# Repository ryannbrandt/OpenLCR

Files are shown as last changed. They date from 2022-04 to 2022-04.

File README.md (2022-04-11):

# OpenLCR
The goal of this project is to produce an accurate, inexpensive, open-source LCR meter with an original design.

- What is an LCR meter?

A device that measures inductance (L), capacitance (C), and resistance (R).  Typically, LCR meters also measure secondary parameters of circuit components such as equivalent series resistance, quality factor, and leakage resistance.

- How are these quantities measured?

Generally, an LCR meter needs to measure impedance.  A common way of doing this is to apply a known voltage or current to the unknown device under test, and then measure the uncontrolled quantity (current or voltage, respectively) that results.  If the input is sinusoidal at a set frequency, the ratio of the voltage and current amplitudes gives the magnitude of the impedance.  The difference in phase between the two gives the phase of the impedance.  For metrology purposes, this measurement will often just be taken at a single precise frequency, such as 100 Hz, 120 Hz, 1 kHz, 10 kHz, or 100 kHz.  Alternatively, you can measure impedance at many different frequencies and generate a plot of Z vs f.  Either way, this information, combined with a model for the device under test, can be used to calculate model parameters.  In the simplest nontrivial case, a model may consist of a series inductance and resistance (in the case of an inductor), a series capacitance and resistance (in the case of a capacitor), or a network of series RL and parallel C (for a resistor).

- Why make an LCR meter?

I studied analog circuit design for most of my advanced coursework in electrical engineering.  More recently, I took some coursework in microcontrollers.  Along the way, I've gained an appreciation for measurement instrumentation.  I wanted to work on a project that combined all of these topics.  The challenge of precisely measuring component parameters is well-suited for this goal.  It has a well-defined problem and straightforward measurement technique, but the devil is in the details.  Finding suitable components, evaluating them for this application, and just making it work is a valuable exercise in system-level electronics design and prototyping.  Also, being able to take these measurements is useful when making circuits like filters (for which precisely matched resistors and capacitors are essential) or high-frequency circuits (for which characterizing parasitics is essential for accurate modeling).  Regardless of these practical applications for LCR meters, this measurement challenge is just fun!

- Don't low-cost LCR meters already exist?

Probably.  I did a bit of market research at the beginning of this project and was able to find devices that measure L, C, and R along with secondary parameters and even transistor and diode characterization for as little as $30 on Amazon.  The accuracy of such low-cost instruments is not clear though (they make no claims regarding accuracy, have no calibration certification, and contain no datasheet or user manuals), though most devices only display enough information to possibly provide 1% accuracy.  One $30 device I found can measure inductance from 10 uH to 20 H, capacitance from 25 pF to 0.1 F, and resistance from 0.5 ohm to 50 Mohm.  Higher quality devices appear to be available such as battery-powered, handheld, calibrated instruments for $300-$500, including smart tweezers (meant for characterizing primary characteristics and parasitics of surface mount components).  Those instruments claim accuracy on the order of 0.3%.  The range of measured values is something like 1 uH to 1000H for inductors, and unspecified for C and R.  Finally, the highest quality devices are bench-top, rack-mounted, metrology-grade LCR meters.  These devices range in cost from $3,000 (usually used) to $12,000.  Their accuracy is as high as 0.02%, can measure 0.01 mohms to 10 Tohms for R, 0.1 pH to 10GH for L, and 0.1 zF to 10 kF for C.  
[Source](https://www.ietlabs.com/pdf/Datasheets/1693.pdf)

I think it will be interesting to see how accurate of an instrument I can make using a modest budget.  Let's find out!

## Design  (Last updated 4/10/2022)

Here are the circuit schematics for the latest version of the design:

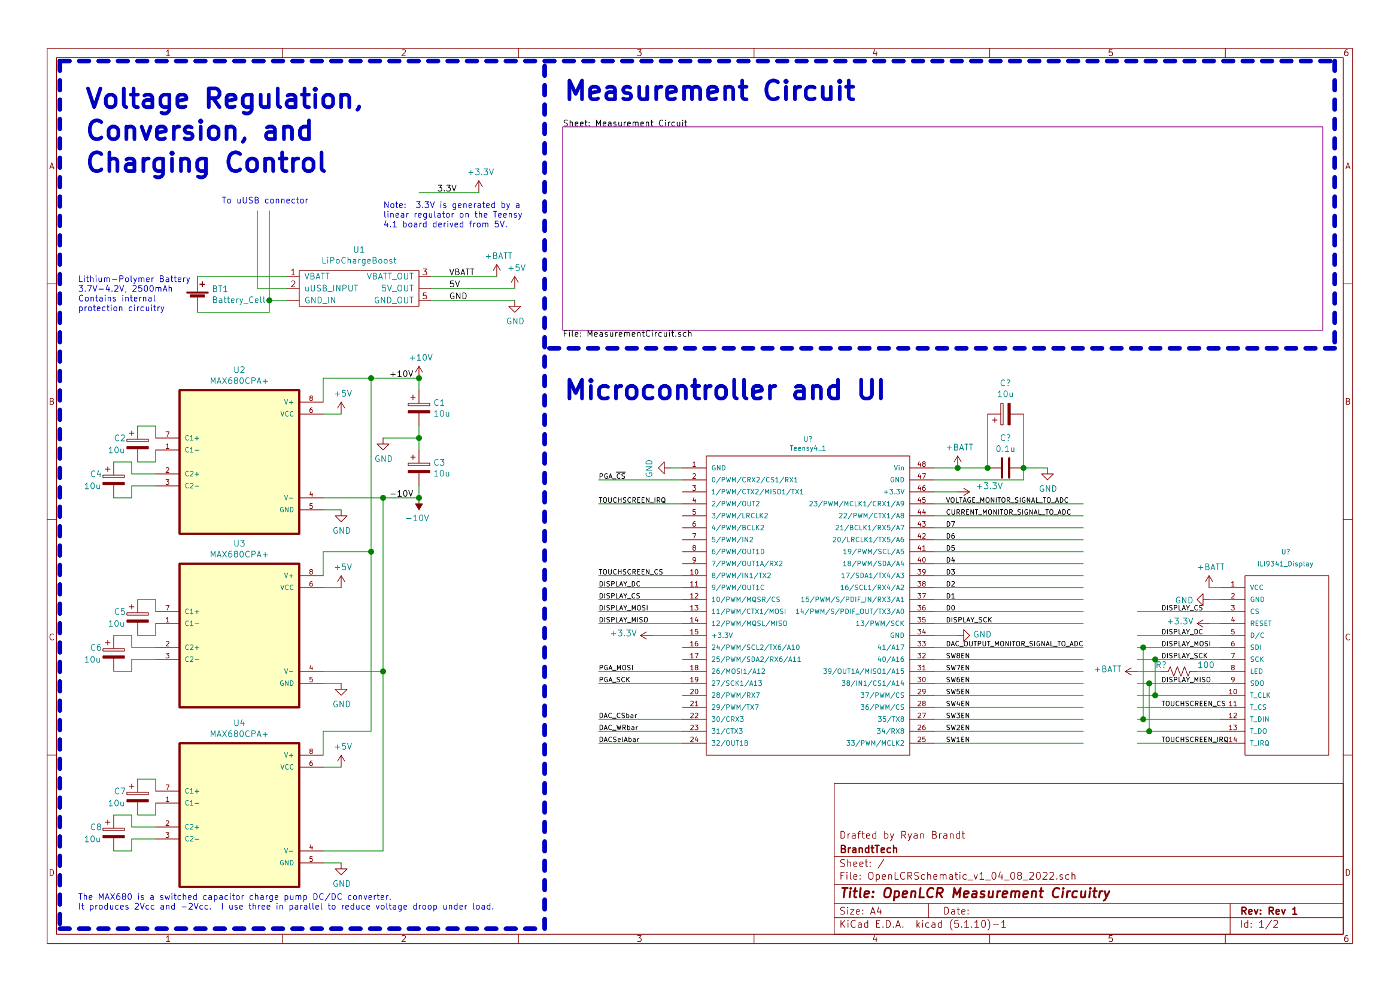
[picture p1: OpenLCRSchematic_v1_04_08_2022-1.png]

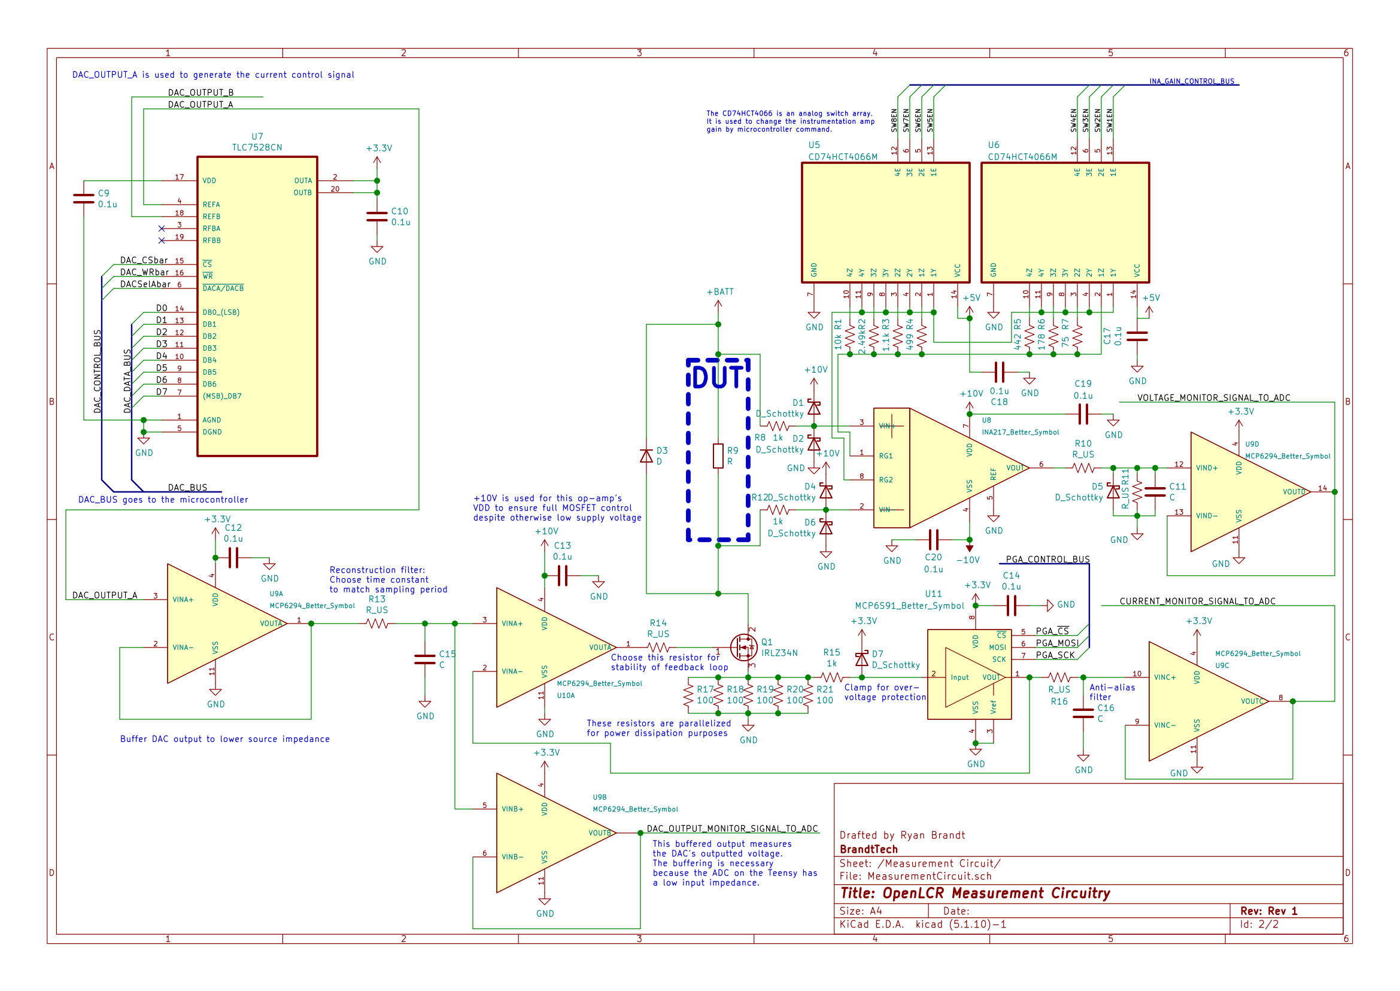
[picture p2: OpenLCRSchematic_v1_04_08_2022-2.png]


A short description of the principle of operation is this:

To measure impedance, the instrument acts as a current source to the device under test.  The voltage across the DUT that results is measured using an instrumentation amplifier.  The current through the device is measured by measuring the voltage across a shunt resistor that is in series with the DUT.  The current source is controllable by a voltage that is generated by a digital to analog converter.  The voltage generated by the DAC is also measured for calibration purposes.  All measured voltages are sent to separate analog to digital converter channels which are internal to the microcontroller, a Teensy 4.1.  To measure a large dynamic range of impedances, the instrumentation amplifier has a digitally programmable gain, implemented by switching the gain-setting resistor with analog switch arrays.  To generate a large dynamic range of currents, a programmable gain amplifier is used in the current-setting feedback loop.  The PGA gain is controlled via SPI.

Since the device is to be battery operated, we have several integrated circuits for generating necessary voltages to operate the many ICs used in the measurement circuitry.  First, a boost converter generates 5V from the LiPo's 3.7-4.2V.  Next, the Teensy itself contains a 3.3V LDO regulator.  To operate the instrumentation amplifier and power the MOSFET-driving current-controlling op-amp, +/-10V are generated using paralleled charge pump DC/DC converters.

For user-interfacing, there is a touch-screen display.  Recommended on the PJRC website (makers of Teensy) is the 320 x 240 pixel TFT display based on the ILI9341 controller chip.

All my parts have come in and I'm ready to start testing!  I'm concerned about the stability of the current-setting control loop, especially for high PGA gains and large capacitive and inductive loads.  This will be interesting to investigate.

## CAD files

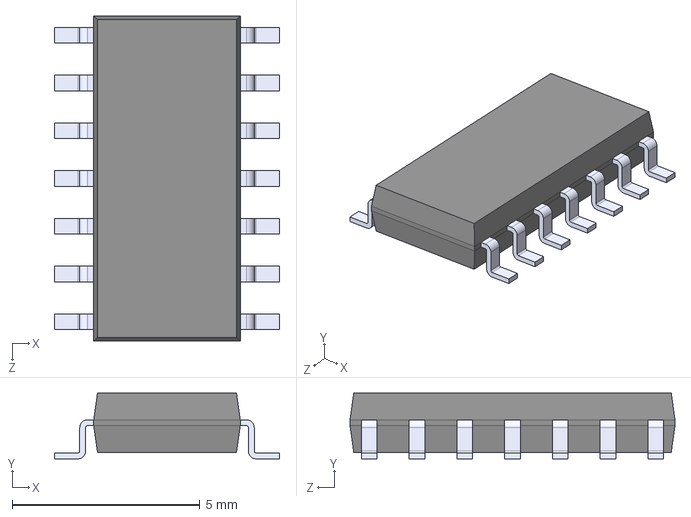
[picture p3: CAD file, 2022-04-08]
OpenLCRSchematic_v1_04_08_2022/CD74HCT4066M/CD74HCT4066M.step
6.00 x 1.75 x 8.65 mm

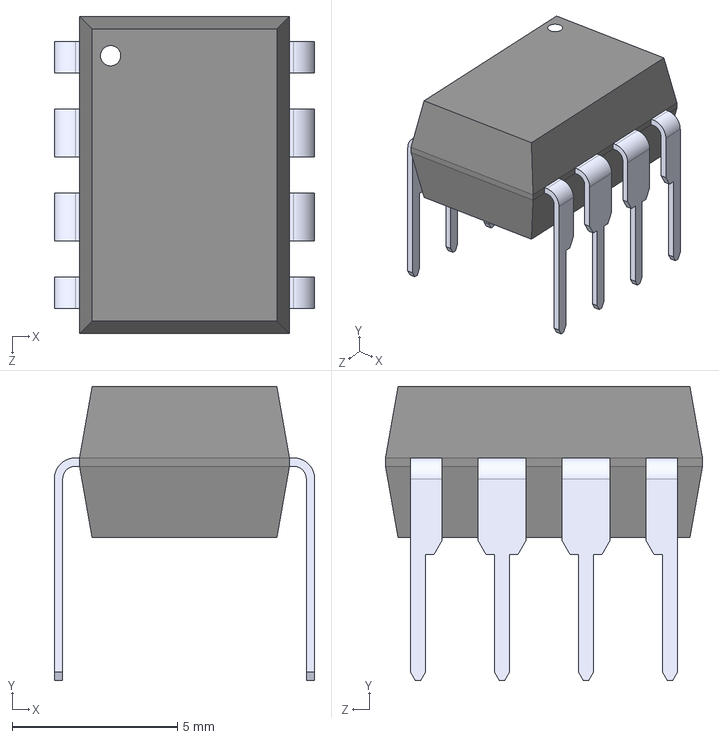
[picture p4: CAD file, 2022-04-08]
OpenLCRSchematic_v1_04_08_2022/INA217AIP/INA217AIP.step
7.87 x 8.89 x 9.59 mm

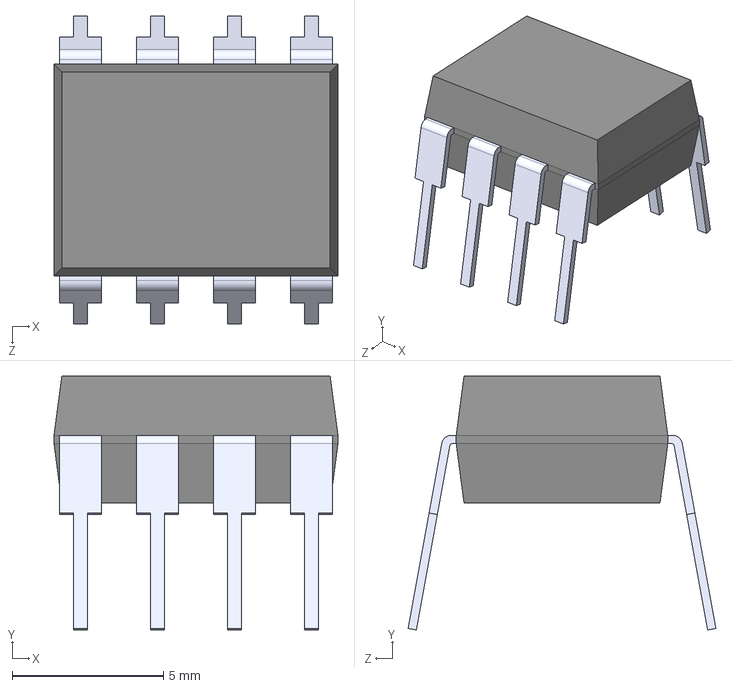
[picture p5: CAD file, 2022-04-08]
OpenLCRSchematic_v1_04_08_2022/MAX680CPA_/MAX680CPA_.step
9.38 x 8.38 x 10.2 mm

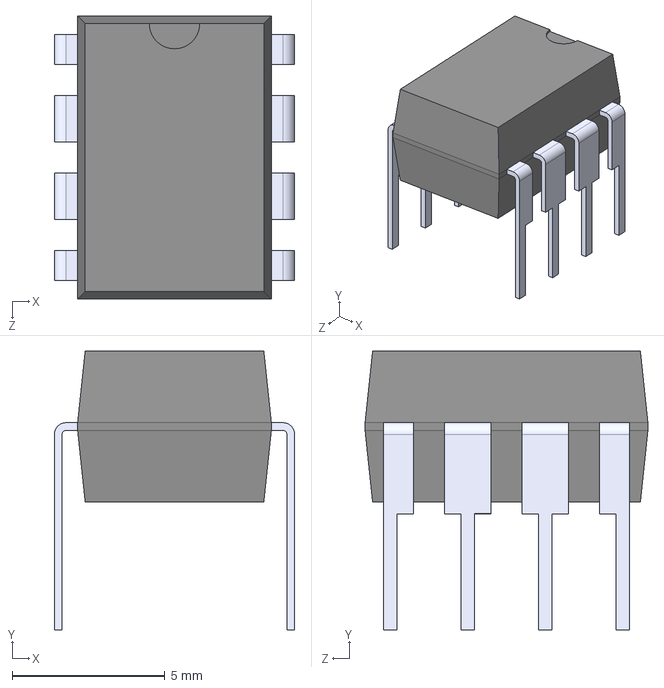
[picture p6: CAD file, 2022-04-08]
OpenLCRSchematic_v1_04_08_2022/MCP6S91-E_P/MCP6S91-E_P.step
7.87 x 9.14 x 9.27 mm

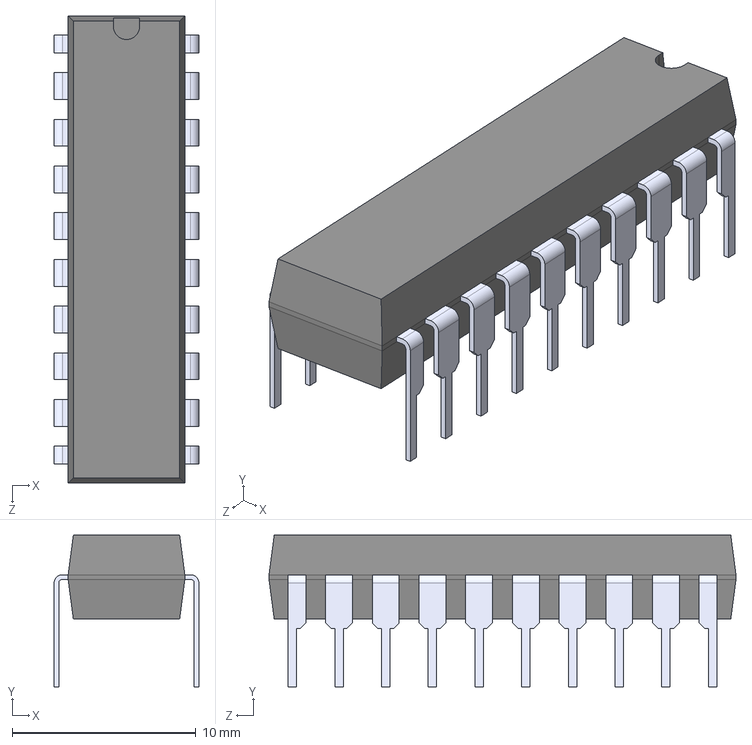
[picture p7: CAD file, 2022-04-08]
OpenLCRSchematic_v1_04_08_2022/TLC7528CN/TLC7528CN.step
7.87 x 8.26 x 25.4 mm

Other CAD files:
OpenLCRSchematic_v1_04_08_2022/MCP6294-E_SL/MCP6294-E_SL.step

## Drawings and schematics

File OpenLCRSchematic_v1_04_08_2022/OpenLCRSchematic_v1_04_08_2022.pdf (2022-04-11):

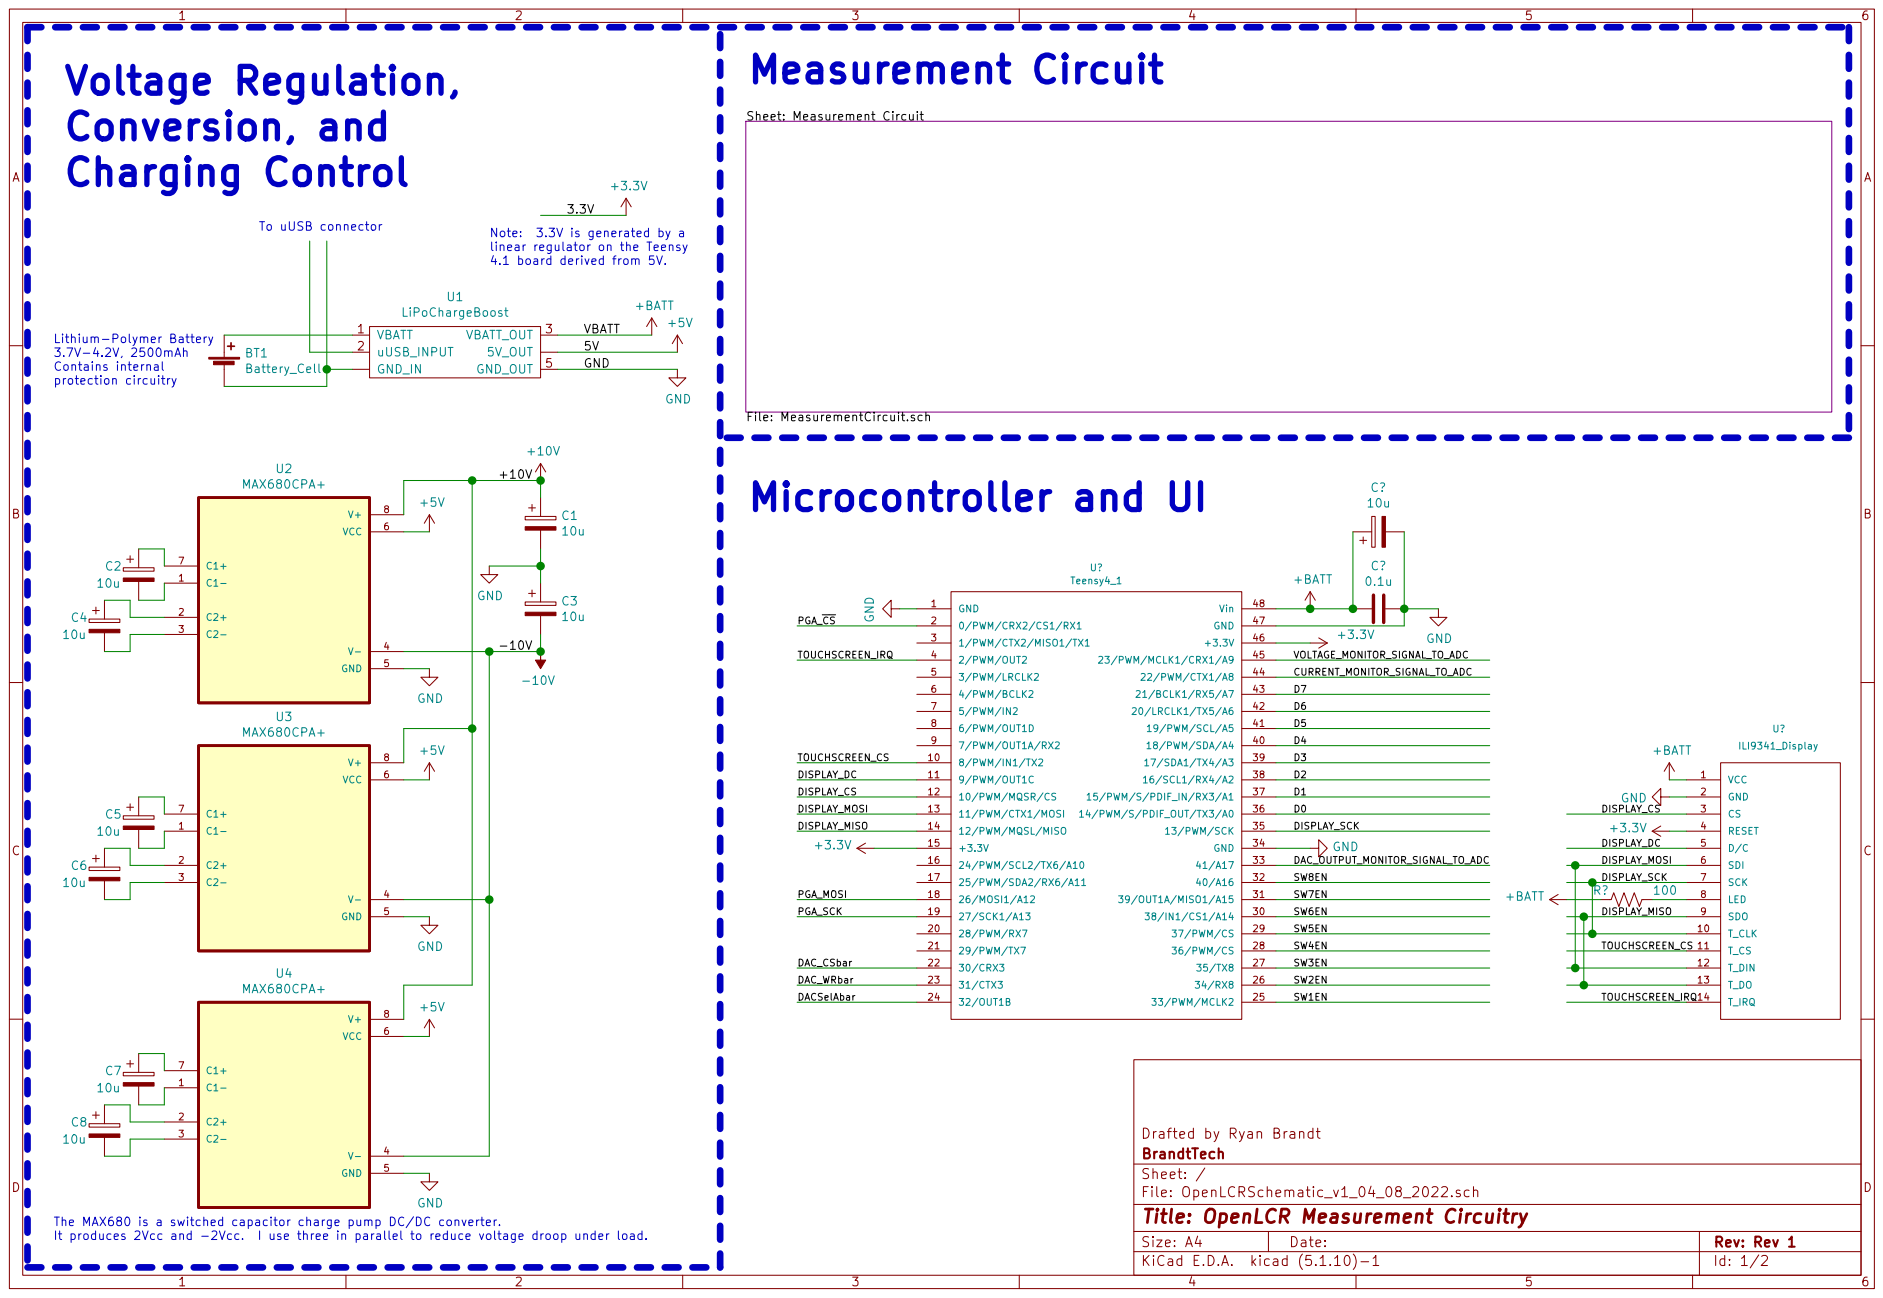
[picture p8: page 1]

linear regulator on the Teensy 4.1 board derived from 5V. Voltage Regulation,
Conversion, and
Charging Control

Note: 3.3V is generated by a

Lithium-Polymer Battery 3.7V-4.2V, 2500mAh Contains internal protection circuitry

File: OpenLCRSchematic_v1_04_08_2022.sch Sheet: / BrandtTech Drafted by Ryan Brandt

Id: 1/2 Title: OpenLCR Measurement Circuitry

The MAX680 is a switched capacitor charge pump DC/DC converter.
It produces 2Vcc and -2Vcc. I use three in parallel to reduce voltage droop under load.

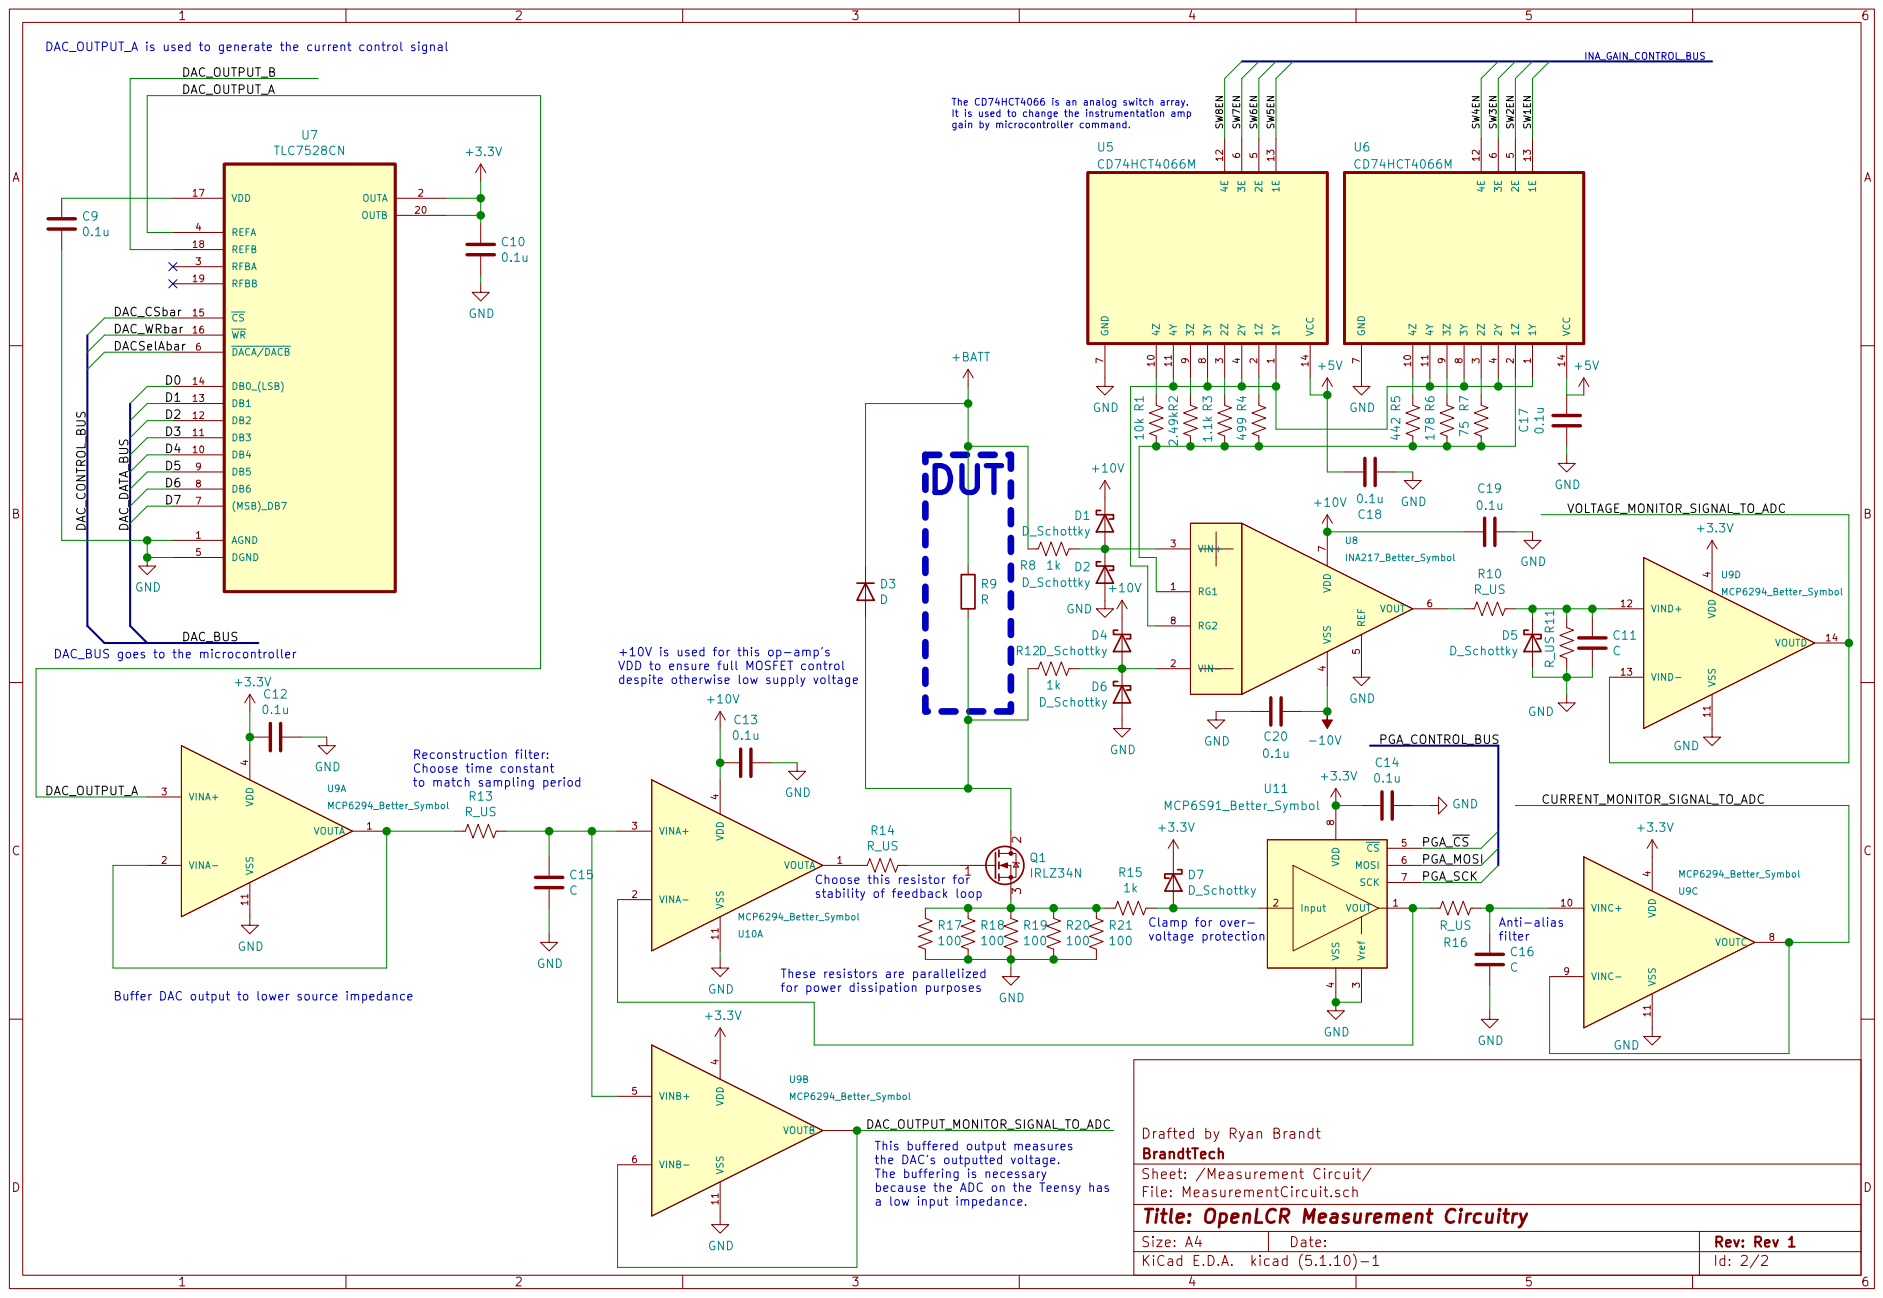
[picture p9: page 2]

It is used to change the instrumentation amp
gain by microcontroller command.
File: MeasurementCircuit.sch Sheet: /Measurement Circuit/ BrandtTech Drafted by Ryan Brandt R4 499 R15

4 VINC+ 10 VOUTC 8 VINC- 9 U9CMCP6294_Better_Symbol RG1 1 VIN- 2 VIN+ 3 VSS

DAC_BUS goes to the microcontroller

+10V is used for this op-amp's VDD to ensure full MOSFET control despite otherwise low supply voltage
0.1u +10VVSS 11 VDD

4 VOUTA 1 VINA- 2 VINA+ 3 U9AMCP6294_Better_Symbol D7D_Schottky GND

voltage protection Reconstruction filter: Choose time constant

to match sampling period

4 VINB+ 5 VINB- 6 VOUTB U9BMCP6294_Better_Symbol VSS 11 VDD

4 CS 5 MOSI 6 SCK 7 VDD

a low input impedance. Choose this resistor for stability of feedback loop

These resistors are parallelized
for power dissipation purposes
+3.3V GND

This buffered output measures
the DAC's outputted voltage.
The buffering is necessary
because the ADC on the Teensy has

Id: 2/2 Title: OpenLCR Measurement Circuitry

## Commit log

2022-04-08 KiCAD libraries and power schematic
    Add KiCAD libraries for components
    Create schematic with power section
    [CD74HCT4066M.step, INA217AIP.step, MAX680CPA_.step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]
2022-04-09 Measurement Circuit Update
    Update measurement circuit
    [MeasurementCircuit.sch, OpenLCRSchematic_v1_04_08_2022.sch]
2022-04-10 Add bypass capacitors for ICs
    Add some bypass caps for the ICs
    [MeasurementCircuit.sch]
2022-04-10 Make Teensy 4.1 symbol
    Add the Teensy 4.1 circuit symbol to the schematic. Still not exactly sure on what pin assignments I'll use.
    [OpenLCRSchematic_v1_04_08_2022.sch]
2022-04-11 Add Connections to Microcontroller
    Add ILI9341 display and microcontroller connections.
    [OpenLCRSchematic_v1_04_08_2022.sch]
2022-04-11 Add schematic images
2022-04-11 Update README.md
    Attempt to add circuit schematics
2022-04-11 Update Readme
    Update readme with a short description of the design
    [OpenLCRSchematic_v1_04_08_2022.sch]
